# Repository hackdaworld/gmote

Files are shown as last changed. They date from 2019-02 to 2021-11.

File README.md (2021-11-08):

# GMote
[GMote](https://digidev.de/gmote) - The Generic LoRaWAN Node

GMote stands for Generic Mote.
It is meant to be a flexible (i.e. applicable in different scenarios for different purposes utilizing different sensors) IoT Node using the LoRa wireless data communication technology. 

The first GMote test version

The first test version was based on the Arduino Pro Mini, which requires very low power if you remove the LED and bypass the power regulator.
Once this proved to be a good idea, a slim version of the Mini Pro board (i.e. the ATMega 328PB) has been integrated and routed on the GMote circuit board.
At first, the Dragino LoRa Bee was the transceiving unit since we had good results with respect to range and usability.
In later versions, the relevant HopeRF modem (RFM95) chip was likewise integrated on the board due to availability and price. 

There are two PCB versions, a small and a mini version, which provide different amount of pin headers to connect various sensors or even actuators. 
Development of an ARM Cortex M0 based version is in progress.

The node is configurable via UART and (planned) LoRaWAN download frames.

It started within the Arduino framework and, as far as the AVR version is concerned, will stick to it to not loose the huge developer community.

## Most important

GMote is meant to become an all-purpose LoRaWAN node (and in fact a whole eco system).
Moreover, the design, hardware, firmware and software of the GMote project is open source and free to use without any restriction.
To enable everyone to participate, everything is kept as simple as possible, ranging from the low-level PCB design and firmware up to the high-level IoT platform app.

Since it aims to become a project for a hopefully huge community, let the GMote developers know what you think about it, about problems that occured, additional features that you require and everything you would like to have changed in the current realization. 
Anything on your mind?
Maybe to remove the RTC in favor of the internal watchdog timer to make the board even more simple (thereby accepting some inaccuracy in the periodicity of frames)? 
No I2C pinout or at least another version without?
A voltage regulator for a well defined supply but a shorter battery lifetime in return?
Whatever it is, let us know!

## Requirements

* ISP programmer, e.g. the [Pocket AVR Programmer](https://www.digikey.de/product-detail/de/sparkfun-electronics/PGM-09825/1568-1080-ND/5230949), to upload the firmware or an optional Arduino bootloader as you please.
* USB to serial converter (3.3V), e.g. the [FT231X Breakout](https://www.digikey.de/product-detail/de/sparkfun-electronics/BOB-13263/1568-1720-ND/7675364) for optionally uploading the firmware the Arduino way (via boot loader) and for serial communication and configuration. Strictly speaking, this is not required, since you could configure the node (i.e. program the EEPROM) via ISP. However, it is strongly suggested!
* A board (see below) produced by your favorite PCB manufacturer.
* The parts listed in the respective bill of materials.
* Soldering iron and solder.

## Hardware

### PCB

Small and mini version of the GMote LoRaWAN node

There are currently two versions ([small](pcb/small) and [mini](pcb/mini)) of the GMote LoRaWAN node, which are based on the ATMega 328PB and run quite reliably.
Moreover, there is one based on the [ARM MCU](pcb/arm), which is in very early stage and comes without any guarantee to work. We mean it!

You can find the available PCBs in the respective [PCB](pcb) directory
together with further details as well as the bill of materials and respective [DigiKey](https://www.digikey.de/) part numbers.

The boards are designed with [KiCad](http://kicad.org/).
A lot of PCB manufacturers directly support the KiCad PCB files.

The size of the SMD parts was chosen to be 0805 (2012) and hand soldering pads were used for the resistors and capacitors so you can DIY at home with a low cost soldering iron.
Caution: Patience required!

:warning: :warning:
The ATMega based boards are missing a pullup at the chipselect signal of the LoRa modem.
Please find details and a workaround in the [firmware section](#firmware).
:warning: :warning:

### Battery

The popular JST connector is used to connect the battery.
It is directly wired to VCC of the used ICs, no voltage regulator no polarity protection diodes!
Thus, be extremely careful when connecting your power supply.

GMote runs nicely with 3.7V LiPo batteries.
Higher voltages were not tested, so don't use higher voltages!
If you don't use the moisture or ultrasound distance sensor (these seem to require more than 3.3V), you can even run it with two AA(A) batteries (3V) or even accus (~2.8V).

## Firmware

All files can be found in the [firmware](firmware) location. 

### AVR ATMega 328PB fimrware

So far, you need the [Arduino IDE](https://www.arduino.cc/en/Main/Software) to build the firmware.
Moreover, the [LMIC library](https://github.com/matthijskooijman/arduino-lmic) is currently used to implement LoRaWAN.
Please follow the [instructions](https://github.com/matthijskooijman/arduino-lmic/#Installing) to include this library in your Arduino IDE.

Now you can build the firmware from the Arduino Sketch, [m328pb.ino](./firmware/mega328pb/m328pb.ino).\
Comment or uncomment the line
```c
#define PCB_MINI
```
in the very beginning of the sketch depending on the board you chose.

Alternatively, feel free to use one of the precompiled binaries.\
Mini: [m328pb_mini.hex](firmware/mega328pb/m328pb_mini.hex)\
Small: [m328pb_small.hex](firmware/mega328pb/m328pb_small.hex)

Since you build a GMote device from scratch, you start with a plain Atmega328P without an installed Arduino bootloader.
Use the ISP programmer and the [avrdude](https://www.nongnu.org/avrdude/) software to program either an optional Arduino bootloader or upload the GMote firmware directly.
To upload the firmware directly using the Pocket AVR Programmer, do
```
avrdude -patmega328pb -cusbtiny -v -Uflash:w:/path/to/m328pb_mini.hex:i
```
and adjust the path to the firmware hex file.
For disablinge the clock divider, which you have to do, run:
```
avrdude -patmega328pb -cusbtiny -v -Ulfuse:w:0xe2:m
```

:warning: :warning:
A pullup is required at the chipselect signal of the LoRa modem (pin 5 of the HopeRF or pin 14 of the ATMega).
Without it, programming the firmware or setting the fuse bits only works randomly because of the SPI LoRa modem disturbing the ISP programming process.
I am not sure why I didn't recognize this for the first few test devices.
Either there a different versions of the modem where some of them have an integrated pullup or it was simply by chance. 
I helped myself with a short wire applying VCC to the above mentioned pin during programming and setting the fuse bits.
There will be no board revision just fixing this bug since a new board is planned anyways.
Sorry for the inconvenience!
:warning: :warning:

### STM32F051 firmware

The version currently in development will be based on the *STM32F051K8T6* ARM Cortex M0 IC MCU operating at 48Mhz with 64KB FLASH and 8KB of embedded SRAM.

[Apache MyNewt](https://mynewt.apache.org/) as well as [Mbed OS](https://www.mbed.com/) are considered as an OS.

* MyNewt: First attempts can be found in [firmware/mynewt](firmware/mynewt) 
* Mbed OS: nothing yet ...

We keep you posted ...

## Sensors

Next to the very basic digital input sensing and ADC meassurements on the availabe IO and ADC pins, there are a couple of other sensors which require a slightly more special treatment.
At the moment, these are the ultrasound distance and the capacitive soil moisture sensor.

Soil moisture and ultrasound distance sensor

These are sensors you probably know already and where to buy them.
They were not designed by the GMote team.

However, in order to reduce costs and to simplify things, yet another soil moisture sensor based on the infamous *74HC14* hex inverting Schmitt trigger has been designed.
Here we go: [GMote Soil Moisture Sensor](pcb/sms).

## Utils and configuration

The GMote device is configured via the serial interface utilizing the USB to serial converter.
you can find the source code as well as installation and usage instructions in the [utils](utils) directory.

## Cases

To cover GMote and its sensors, a case was designed using [OpenSCAD](http://www.openscad.org/).
At the moment, the ultrasound distance and capacative moisture sensors are considered.

GMote Cases and sensors for illustration

The image illustrates the idea of the case and sensors.
Details and files can be found in the [cases](cases) directory.

## Backend 

ToDo

## Software 

ToDo

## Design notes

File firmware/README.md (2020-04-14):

# Firmware

## AVR ATMega328PB

Arduino Sketch: [m328pb.ino](mega328pb/m328pb.ino)

Precompiled binaries: [m328pb_mini.hex](mega328pb/m328pb_mini.hex) and [m328pb_small.hex](mega328pb/m328pb_small.hex)

## STM32 Cortex M0

First attempts porting [Apache MyNewt](https://mynewt.apache.org/) to the ARM based GMote board is located in [mynewt](mynewt).

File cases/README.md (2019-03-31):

# Cases

## Tasks

- [x] OpenSCAD and STL files of the Mini version
- [ ] Print and verify Mini version

## Mini 900

Case for the GMote Mini version suitable for batteries with dimensions not exceeding 48x32x6 mm .
I used a 900 mAh LiPo battery, that's where the 900 comes from.

The whole case consists of multiple parts, which you can all find within the *mini_900.scad* or the *mini_900.stl* file.
If your 3D printer or print service does not support multiple parts in one file, there are
- *mini_800_bottom.stl* for the bottom
- *mini_800_top.stl* for the top
- *mini_800_us_closing.stl* for the ultrasound sensor closings
- *mini_800_ms_closing.stl* for the moisture sensor closing
of the case.

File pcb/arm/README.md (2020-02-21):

# GMote on ARM
[GMote](https://digidev.de/gmote) - Generic LoRaWAN Node

## Schematics

Schematic of GMote on ARM

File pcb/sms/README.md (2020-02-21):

# GMote soil moisture sensor

## Bill of materials

| Designator | Quantity  | Part | DigiKey |
| --- | --- | --- | --- |
| R1 | 1 | R 0805 100k | | 
| R2 | 1 | R 0805 100 | | 
| C1 | 1 | C 0805 10u | | 
| J1 | 1 | Pin Header 2.54 | | 
| U1 | 1 | SOIC-14 74HC14  | | 

## Schematics

Schematic of GMote Soil Moisture Sensor

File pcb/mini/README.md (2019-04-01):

# GMote Mini
[GMote](https://digidev.de/gmote) - Mini Version of the Generic LoRaWAN Node

## Bill of materials

| Designator | Quantity  | Part | DigiKey |
| --- | --- |--- | --- |
| U1 | 1 | RFM95W-868S2 | 1597-1488-ND / RFM95W-915S2-ND |
| J2 | 1 | AVR-ISP-6 | 952-2121-ND |
| C1 | 1 | 10uF C | 1276-2399-1-ND |
| C2/3/4/7/8 | 5 | 0.1uF C | 399-9158-1-ND |
| J1 | 1 | 2 Pin Conn | 455-1704-ND |
| J3 | 1 | 9 Pin Conn | Pin Header or Screw Terminal |
| J6 | 1 | U.FL SMT | CONUFL001-SMD-TCT-ND |
| J9 | 1 | 1 Pin Conn | optional 7.6 cm antenna wire |
| JP1/2 | 2 | 2 Pin Conn | 952-2262-ND |
| R1/2/3 | 3 | 10k Resistor | RR12P10.0KDCT-ND |
| U2 | 1 | PCF8563 RTC  | 568-6650-1-ND |
| U3 | 1 | ATMEGA328PB  | ATMEGA328PB-AU-ND |
| Y2 | 1 | 32.768kHz | 535-10248-1-ND |
| J2 | 1 | 6 Pin Conn | 609-3263-ND |

## Schematics

Schematic of GMote Mini

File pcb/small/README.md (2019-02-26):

# GMote Small
[GMote](https://digidev.de/gmote) - Small Version of the Generic LoRaWAN Node

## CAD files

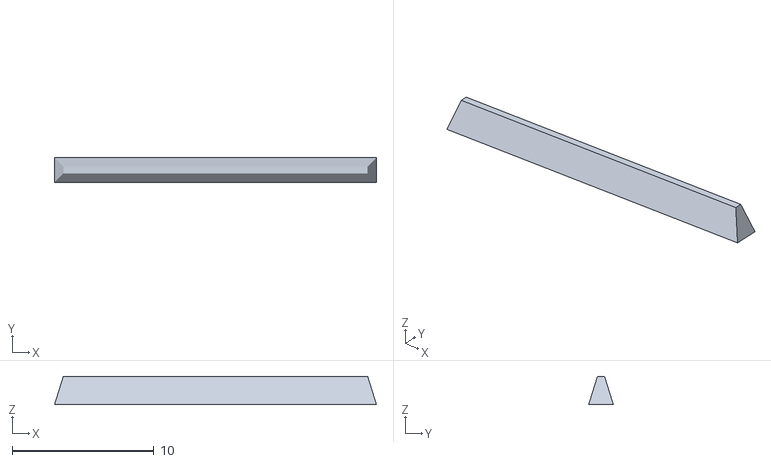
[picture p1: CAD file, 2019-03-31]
cases/mini_900_ms_closing.stl
22.8 x 1.75 x 2.01

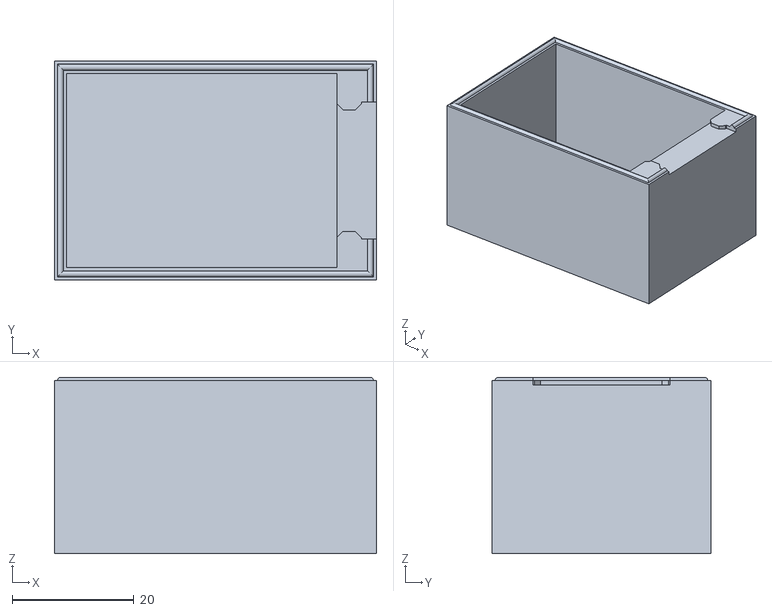
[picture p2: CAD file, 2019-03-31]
cases/mini_900_bottom.stl
53.0 x 36.0 x 29.0

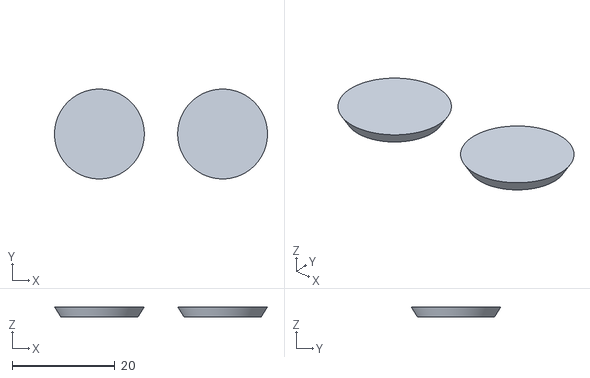
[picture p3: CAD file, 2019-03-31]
cases/mini_900_us_closing.stl
41.5 x 17.5 x 2.00

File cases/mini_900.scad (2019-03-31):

$fa=0.05;
$fs=0.05;

delta=0.01;
dfit=0.5;

bwd=2;

// moisture sensor
ms_l=86;
ms_w=22;
ms_t=1;
ms_rl=20.5;
ms_rlo=4.5;
ms_rli=2.5;
ms_rd=1.5;
ms_lt=96;
ms_cl=10;
ms_cw=10;
ms_ch=6;
ms_inside=25;
ms_rt=5*ms_t;

// us sensor
us_x=44;
us_y=20;
us_z=1.5;
us_r=16/2;
us_dx=10;
us_sh=13;

//bat_x=47;
bat_x=dfit+us_x+ms_rlo;
bat_y=32;
bat_z=6;

brd_x=34;
brd_y=25;
brd_z=25;

brd_rest_z=4;
brd_rest_y=2;
brd_t=1;


lockr=0.5;

ms_sh=bat_z+brd_z+2*bwd-ms_ch-ms_t/2;

module shim(w1,w2,d,h) {
	linear_extrude(height=h)
	polygon(points=[[-w1/2,0],[w1/2,0],[w2/2,d],[-w2/2,d]]);
}

module lock(x,y,rad) {
	translate([0,0,0]) rotate([0,90,0])
	cylinder(r=rad,h=x);
	translate([0,0,0]) rotate([-90,0,0])
	cylinder(r=rad,h=y);
	translate([x,0,0]) rotate([-90,0,0]) 
	cylinder(r=rad,h=y);
	translate([0,y,0]) rotate([0,90,0])
	cylinder(r=rad,h=x);
	intersection() {
		translate([-rad,0,0]) rotate([0,90,0])
		cylinder(r=rad,h=x+2*rad);
		translate([0,-rad,0]) rotate([-90,0,0])
		cylinder(r=rad,h=y+2*rad);
	}
	intersection() {
		translate([-rad,0,0]) rotate([0,90,0])
		cylinder(r=rad,h=x+2*rad);
		translate([x,-rad,0]) rotate([-90,0,0]) 
		cylinder(r=rad,h=y+2*rad);
	}
	intersection() {
		translate([x,-rad,0]) rotate([-90,0,0]) 
		cylinder(r=rad,h=y+2*rad);
		translate([-rad,y,0]) rotate([0,90,0])
		cylinder(r=rad,h=x+2*rad);
	}
	intersection() {
		translate([-rad,y,0]) rotate([0,90,0])
		cylinder(r=rad,h=x+2*rad);
		translate([0,-rad,0]) rotate([-90,0,0])
		cylinder(r=rad,h=y+2*rad);
	}
}

module fullcase02(dbg_x,dbg_y,dbg_z) {

// body
difference() {
	hull() {
		cube([bat_x+2*bwd,bat_y+2*bwd,bat_z+2*bwd+brd_z+bwd]);
	}
	union() {
		// volume
		translate([bwd,bwd,bwd])
			cube([bat_x+dbg_x,bat_y,bat_z+bwd+brd_z+dbg_z]);
		// moisture sensor slot
		translate([bat_x+bwd-delta,bwd+(bat_y-ms_w)/2-dfit/2,bat_z+2*bwd+brd_z-ms_ch-ms_t-dfit/2])
			cube([bwd+2*delta,ms_w+dfit,ms_t+dfit]);
		// us sensor openings
		translate([bwd+dfit+us_dx,bwd+dfit+us_y/2,bat_z+brd_z+2*bwd-delta]) {
			cylinder(r=us_r+dfit/2,h=bwd+2*delta);
			translate([us_x-2*us_dx,0,0])
				cylinder(r=us_r+dfit/2,h=bwd+2*delta);
		}
		// text
		translate([2.5*bwd,1.55*(bat_y/2+bwd),bat_z+brd_z+2.75*bwd])
		linear_extrude(height=bwd/4+delta)
				text("GMote",
				     font="Liberation Sans:style=Bold Italic",
				     valign="center",
				     size=8
				);
		translate([bat_x-1.8*bwd,1.5*bat_y/2,bat_z+brd_z+2.75*bwd])
		rotate([0,0,90])
		linear_extrude(height=bwd/4+delta)
				text("Mini",
				     font="Liberation Sans:style=Bold Italic",
				     valign="center",
				     size=3
				);
	}
}

// sensor rest (moisture)
translate([bat_x+2*bwd-(ms_inside-ms_rl),0,bat_z+brd_z+2*bwd-ms_ch-ms_t-ms_rt/2]) {
	// moisture
	hull() {
		translate([-(ms_rlo-dfit)/2,0,0])
			cube([ms_rlo-dfit,delta,ms_rt]);
		translate([0,bwd+(bat_y-ms_w)/2,0])
			shim(ms_rlo-dfit,ms_rli-dfit,ms_rd-dfit,ms_rt);
	}
	translate([0,bwd,0])
		cube([ms_inside-ms_rl,(bat_y-ms_w)/2-dfit/2,ms_rt]);
	hull() {
		translate([-(ms_rlo-dfit)/2,bat_y+2*bwd,0])
			cube([ms_rlo-dfit,delta,ms_rt]);
		translate([0,bat_y+bwd-(bat_y-ms_w)/2,0])
			shim(ms_rlo-dfit,ms_rli-dfit,-ms_rd+dfit,ms_rt);
	}
	translate([0,bat_y+bwd-(bat_y-ms_w)/2+dfit/2,0])
		cube([ms_inside-ms_rl,(bat_y-ms_w)/2,ms_rt]);
	// ground plate
	translate([-(ms_rlo-dfit)/2,0,0])
		cube([ms_inside-ms_rl,bat_y+2*bwd,ms_rt/2-dfit/2]);

	// us additional rest
	/*
	translate([-bat_x-bwd+(ms_inside-ms_rl),bwd,0])
		cube([bwd,bwd,ms_rt]);
	translate([-bat_x-bwd+(ms_inside-ms_rl),us_y,0])
		cube([bwd,bwd,ms_rt]);
	*/
}

}

module case_bottom() {
	intersection() {
		fullcase02(0,0,0);
		cube([100,100,ms_sh]);
	}
	difference() {
		translate([bwd/2,bwd/2,ms_sh])
			lock(bat_x+bwd,bat_y+bwd,lockr);
		translate([bwd,bwd+(bat_y-ms_w)/2-dfit/2,0])
			cube([100,ms_w+dfit,100]);
	}
}

module case_top() {
	translate([0,0,-ms_sh]) {
		//rotate([-110,0,0])
		difference() {
		intersection() {
			fullcase02(0,0,0);
			translate([0,0,ms_sh])
				cube([100,100,100]);
		}
		translate([bwd/2,bwd/2,ms_sh])
			lock(bat_x+bwd,bat_y+bwd,lockr);
		}
	}
}

// sensors

module us_sensor() {
	color("red") 
		cube([us_x,us_y,us_z]);
	color("silver") {
		translate([us_dx,us_y/2,us_z])
			cylinder(r=us_r,h=us_sh);
		translate([us_x-us_dx,us_y/2,us_z])
			cylinder(r=us_r,h=us_sh);
	}
}

module ms_sensor() {
	color("SaddleBrown") {

	difference() {
		cube([ms_l,ms_w,ms_t]);
		union() {
			translate([ms_rl,0,-delta]) {
				hull() {
					shim(ms_rlo,ms_rli,ms_rd,ms_t+2*delta);
					translate([-ms_rlo/2,-1,0])
						cube([ms_rlo,1,ms_t]);
				}
				translate([0,ms_w-ms_rd,0]) hull() {
					shim(ms_rli,ms_rlo,ms_rd,ms_t+2*delta);
					translate([-ms_rlo/2,ms_rd,0])
						cube([ms_rlo,1,ms_t]);
				}
			}
		 }
	}
	// tip
	translate([ms_l-1,0,0]) {
		hull() {
			cube([1,ms_w,ms_t]);
			translate([ms_lt-ms_l,ms_w/2,0]) cube([0.01,0.01,ms_t]);
		}
	}

	}
	color("grey") {
		translate([-ms_cl/2,(ms_w-ms_cw)/2,ms_t])
		cube([ms_cl,ms_cw,ms_ch]);
	}
}

module ms_closing() {
	hull() {
		cube([ms_w+1.5*dfit,ms_t+1.5*dfit,delta]);
		translate([1.25*dfit,1.25*dfit,bwd])
			cube([ms_w-dfit,ms_t-dfit,delta]);
	}
}

module us_closing() {
	cylinder(r2=us_r+1.5*dfit,r1=us_r-dfit,h=bwd);
	translate([us_x-2*us_dx,0,0])
		cylinder(r2=us_r+1.5*dfit,r1=us_r-dfit,h=bwd);
}

// printable

// everything
/**/
translate([0,0,0]) {
	translate([0,bat_y+4*bwd,0]) {
		case_bottom();
	}
	case_top();
	translate([bat_x+4*bwd+us_dx,us_r+bwd,0])
		us_closing();
	translate([bat_x+4*bwd+us_dx,bat_y-2*bwd,0])
		ms_closing();
}
/**/

// bottom
//case_bottom();
// top
//case_top();
// us closing
//us_closing();
// ms closing
//ms_closing();

// showcase

/*
translate([0,2*(bat_y+4*bwd),0]) {
	fullcase02(0,0,0);
	translate([bwd+dfit,bwd+dfit,bat_z+brd_z+2*bwd-us_z-dfit])
		us_sensor();
	translate([bwd+bat_x+bwd+2*dfit,bwd+(bat_y-ms_w)/2-0.75*dfit,ms_sh+ms_t/2+dfit])
		rotate([0,-90,0]) rotate([0,0,90]) ms_closing();
}

translate([0,3*(bat_y+4*bwd),0]) {
	fullcase02(0,0,0);
	translate([bat_x+2*bwd-ms_inside,(bat_y+2*bwd-ms_w)/2,bat_z+brd_z+2*bwd-ms_ch-ms_t])
		ms_sensor();
	translate([bwd+us_dx+dfit,bwd+us_y/2+dfit,bat_z+brd_z+2*bwd+2*dfit]) us_closing();
}

translate([bat_x+6*bwd,bat_y+4*bwd,0]) {
	ms_sensor();
}

translate([bat_x+6*bwd,bat_y+6*bwd+ms_w,0]) {
	us_sensor();
}

translate([bat_x+6*bwd,3.2*(bat_y+4*bwd),ms_ch+ms_t+bwd]) {
	rotate([-180,0,0]) case_top();
}

*/

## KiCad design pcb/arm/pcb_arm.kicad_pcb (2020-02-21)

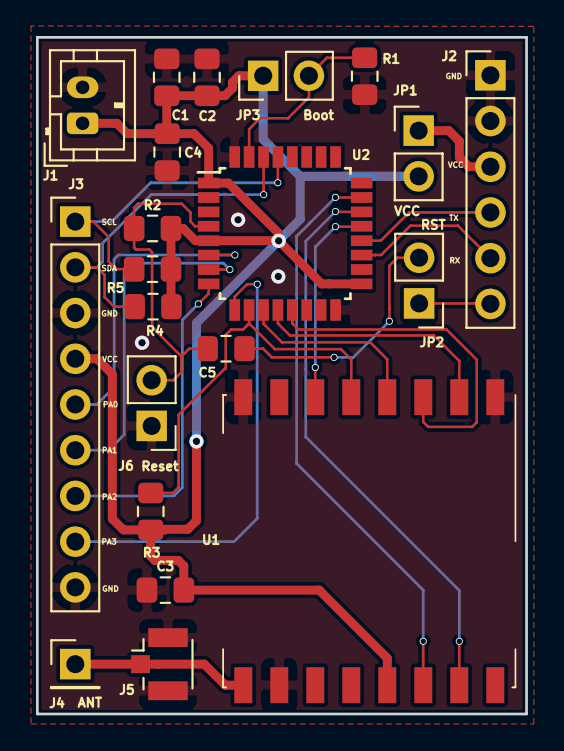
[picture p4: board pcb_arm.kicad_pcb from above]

Board: 2 copper layers, 27.2 x 37.6 mm, 21 parts (0 on the bottom side), 23 nets.

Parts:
C1, C3, C4, C5: 100nF; C_0805_2012Metric_Pad1.15x1.40mm_HandSolder
C2: 10uF; C_0805_2012Metric_Pad1.15x1.40mm_HandSolder
J1: JST_POWER; JST_PH_B2B-PH-K_1x02_P2.00mm_Vertical
J2: 231X_Breakout; PinHeader_1x06_P2.54mm_Vertical
J3: IO_ADC_PINOUT; PinHeader_1x09_P2.54mm_Vertical
J4: ANT_WIRE; PinHeader_1x01_P2.54mm_Vertical
J5: Conn_Coaxial; U.FL_Hirose_U.FL-R-SMT-1_Vertical
J6: RST_PIN; PinHeader_1x02_P2.54mm_Vertical
JP1, JP2, JP3: Jumper; PinHeader_1x02_P2.54mm_Vertical
R1, R2, R3, R4, R5: 10k; R_0805_2012Metric_Pad1.15x1.40mm_HandSolder
U1: RFM95W-868S2; HOPERF_RFM9XW_SMD
U2: STM32F051K8Tx; LQFP-32_7x7mm_P0.8mm

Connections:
231X_RX: J2.5, U2.19
231X_TX: J2.4, U2.20
ANT: J4.1, J5.1, U1.9
ARM_BOOT0: JP3.2, R1.1, U2.31
ARM_RST: C5.1, J6.2, R2.1, U2.4
ARM_SCL: J3.1, R5.1, U2.29
ARM_SDA: J3.2, R4.1, U2.30
GND: C1.2, C2.2, C3.2, C4.2, J1.2, J2.1, J2.2, J3.3, J3.9, J5.2, J6.1, R1.2, U1.1, U1.8, U1.10, U2.16, U2.32
unnamed: J2.3, JP1.1
unnamed: J2.6, JP2.1
PA0: J3.5, U2.6
PA1: J3.6, U2.7
PA2: J3.7, U2.8
PA3: J3.8, U2.9
RFM95_DIO0: U1.14, U2.23
RFM95_DIO1: U1.15, U2.22
RFM95_RST: U1.6, U2.21
RST: C5.2, JP2.2
SPI_MISO: U1.2, U2.12
SPI_MOSI: U1.3, U2.13
SPI_NSS: R3.1, U1.5, U2.10
SPI_SCK: U1.4, U2.11
VCC: C1.1, C2.1, C3.1, C4.1, J1.1, J3.4, JP1.2, JP3.1, R2.2, R3.2, R4.2, R5.2, U1.13, U2.1, U2.5, U2.17

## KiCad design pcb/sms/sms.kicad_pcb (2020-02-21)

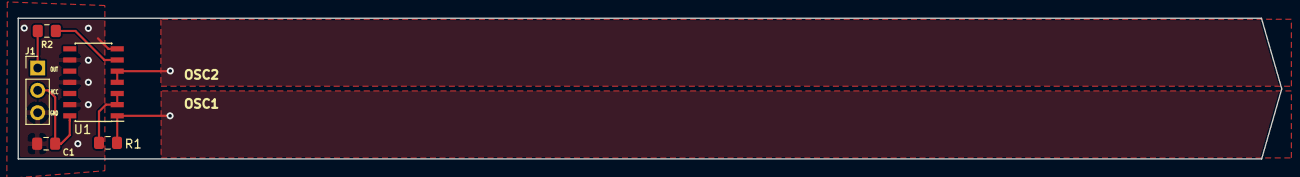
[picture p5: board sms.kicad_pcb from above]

Board: 2 copper layers, 143.7 x 16.0 mm, 5 parts (0 on the bottom side), 7 nets.

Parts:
C1: 10u; C_0805_2012Metric_Pad1.15x1.40mm_HandSolder
J1: Conn_01x03_Male; PinHeader_1x03_P2.54mm_Vertical
R1: 100k; R_0805_2012Metric_Pad1.15x1.40mm_HandSolder
R2: 100; R_0805_2012Metric_Pad1.15x1.40mm_HandSolder
U1: 74HC14; SOIC-14_3.9x8.7mm_P1.27mm

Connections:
GND: C1.2, J1.3, U1.7, U1.9, U1.11, U1.13
unnamed: R1.1, U1.2, U1.3
unnamed: R2.2, U1.6
OSC1: R1.2, U1.1
OSC2: U1.4, U1.5
OUT: J1.1, R2.1
VCC: C1.1, J1.2, U1.14

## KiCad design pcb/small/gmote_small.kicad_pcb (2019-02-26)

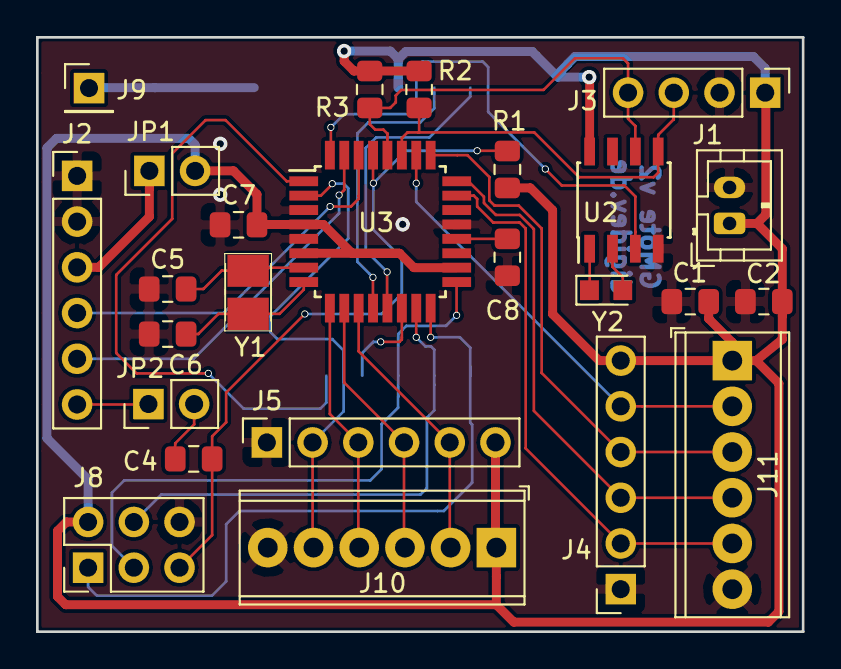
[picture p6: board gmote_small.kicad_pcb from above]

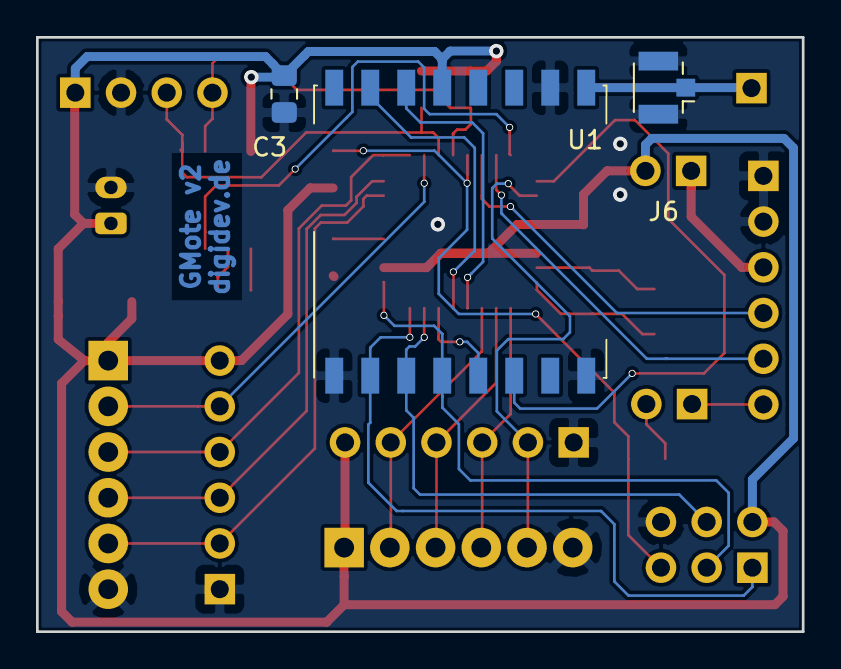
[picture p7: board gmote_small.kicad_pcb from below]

Board: 2 copper layers, 42.5 x 33.0 mm, 28 parts (3 on the bottom side), 32 nets.

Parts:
C1: 10uF; C_0805_2012Metric_Pad1.15x1.40mm_HandSolder
C2, C3, C4, C7, C8: 0.1uF; C_0805_2012Metric_Pad1.15x1.40mm_HandSolder
C5, C6: 16pF; C_0805_2012Metric_Pad1.15x1.40mm_HandSolder
J1: Conn_01x02_Male; JST_PH_B2B-PH-K_1x02_P2.00mm_Vertical
J2: Conn_01x06_Male; PinHeader_1x06_P2.54mm_Vertical
J3: Conn_01x04_Male; PinHeader_1x04_P2.54mm_Vertical
J4: Conn_ADC; PinSocket_1x06_P2.54mm_Vertical
J5: Conn_IO; PinSocket_1x06_P2.54mm_Vertical
J6: Ant_UFL; U.FL_Hirose_U.FL-R-SMT-1_Vertical
J8: AVR-ISP-6; PinHeader_2x03_P2.54mm_Vertical
J9: Conn_01x01_Male; PinHeader_1x01_P2.54mm_Vertical
J10: Screw_Terminal_IO; TerminalBlock_Phoenix_MPT-0,5-6-2.54_1x06_P2.54mm_Horizontal
J11: Screw_Terminal_ADC; TerminalBlock_Phoenix_MPT-0,5-6-2.54_1x06_P2.54mm_Horizontal
JP1, JP2: Jumper; PinHeader_1x02_P2.54mm_Vertical
R1, R2, R3: 10k; R_0805_2012Metric_Pad1.15x1.40mm_HandSolder
U1: RFM95W-868S2; HOPERF_RFM9XW_SMD
U2: PCF8563T; SOIC-8_3.9x4.9mm_P1.27mm
U3: ATmega328P-AU; TQFP-32_7x7mm_P0.8mm
Y1: 8Mhz; Crystal_3.0x2.5_HandSoldering
Y2: 32.768kHz; Crystal_SMD_2012-2Pin_2.0x1.2mm_HandSoldering

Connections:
ADC0: J4.2, J11.5, U3.23
ADC1: J4.3, J11.4, U3.24
ADC2: J4.4, J11.3, U3.25
ADC3: J4.5, J11.2, U3.26
ANT: J6.1, J9.1, U1.9
DTR: C4.1, JP2.2
GND: C1.2, C2.2, C3.1, C5.1, C6.1, C7.1, C8.2, J1.2, J2.1, J2.2, J3.2, J4.1, J5.1, J6.2, J8.6, J10.6, J11.6, U1.1, U1.8, U1.10, U2.4, U3.3, U3.5, U3.21
INT0: U2.3, U3.32
MISO: J8.1, U1.2, U3.16
MOSI: J8.4, U1.3, U3.15
unnamed: C8.1, U3.20
unnamed: J2.3, JP1.1
unnamed: J2.6, JP2.1
unnamed: U2.1, Y2.1
unnamed: U2.2, Y2.2
PB0: U1.14, U3.12
PB1: U1.15, U3.13
PD3: U1.6, U3.1
PD4: J5.2, J10.5, U3.2
PD5: J5.3, J10.4, U3.9
PD6: J5.4, J10.3, U3.10
PD7: J5.5, J10.2, U3.11
RXI: J2.4, U3.30
Reset: C4.2, J8.5, R1.1, U3.29
SCK: J8.3, U1.4, U3.17
SCL: J3.4, R3.2, U2.6, U3.28
SDA: J3.3, R2.2, U2.5, U3.27
SS: U1.5, U3.14
TXO: J2.5, U3.31
VCC: C1.1, C2.1, C3.2, C7.2, J1.1, J3.1, J4.6, J5.6, J8.2, J10.1, J11.1, JP1.2, R1.2, R2.1, R3.1, U1.13, U2.8, U3.4, U3.6, U3.18
XTAL1: C5.2, U3.7, Y1.1
XTAL2: C6.2, U3.8, Y1.2

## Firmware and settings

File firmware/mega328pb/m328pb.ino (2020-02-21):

/*******************************************************************************
   
   GMote - Generic LoRaWAN Node

   Author: frank@hackdaworld.org
   HTTP: https://digidev.de/gmote

   Based on the OTAA TTN example sketch of the lmic Arduino library.
   
 *******************************************************************************/

#include <lmic.h>
#include <hal/hal.h>
#include <SPI.h>

#include <avr/boot.h>
#include <EEPROM.h>

#include <avr/sleep.h>
#include <avr/wdt.h>

#include <Wire.h>

#define MST_DD_VCC  A0
#define MST_DD_OUT  A1

#define PCB_MINI

#ifdef PCB_MINI
  // PCB Mini
  #define LORA_RST  5
  #define US_ECHO   A0
  #define US_TRIG   A1
  #define US_VCC    A2
#else
  // PCB Small
  #define LORA_RST  3
  #define US_ECHO   4
  #define US_TRIG   5
  #define US_VCC    6
#endif

//
// LMIC LoRaWAN stuff
//

// little endian AppEUI
// For TTN issued EUIs the last bytes should be 0xD5, 0xB3, 0x70.
uint8_t APPEUI[8];
#define EEPROM_OFFSET_APPEUI 8
void os_getArtEui (u1_t* buf) {
  for(uint8_t i=0;i<8;i++)
    buf[i]=APPEUI[7-i];
}

// little endian DevEUI
uint8_t DEVEUI[8];
#define EEPROM_OFFSET_DEVEUI 0 
void os_getDevEui (u1_t* buf) {
  for(uint8_t i=0;i<8;i++)
    buf[i]=DEVEUI[7-i];
}

// big endian application key
uint8_t APPKEY[16];
#define EEPROM_OFFSET_APPKEY 16
void os_getDevKey (u1_t* buf) {
  memcpy(buf, APPKEY, 16);
}

// data
static uint8_t data[32];
static uint8_t data_old[32];

// memory for the sendjob function
static osjob_t sendjob;

// Pin mapping
const lmic_pinmap lmic_pins = {
  .nss = 10,
  .rxtx = LMIC_UNUSED_PIN,
  .rst = LORA_RST,
  .dio = {8, 9, LMIC_UNUSED_PIN},
};

//
// GMote configuration & state machine
//

// Serial
uint8_t serGM[10];

// GMote configuration
uint8_t confGM[8];
#define EEPROM_OFFSET_CONFGM 32

/* byte:  7       6    5    4           3           2                    1    0
 *        custom  rfu  rfu  keep alive  sleep time  temperature offeset  rfu  type
 *        
 * rfu: reserved for future use
 * custom: whatever you require
 */

#define SENSOR_TYPE           0
#define TEMP_OFFSET           2
#define SLEEP_TIME            3
#define KEEP_ALIVE            4
#define CUSTOM                7

#define SENSORS_EXT           0
#define SENSOR_ULTRASONIC     0x01
#define SENSOR_IO             0x02
#define SENSOR_LOUDNESS       0x04
#define SENSOR_MOISTURE       0x08
#define SENSOR_MOISTURE_ADC   0x10

#define SENSORS_INT           1
#define SENSOR_BAT_ADC        0x01
#define SENSOR_BAT_TEMP       0x02

// GMote states
uint8_t state=1;
#define STARTUP 1
#define RTC_INITIALIZED 2
#define SENDING 3  
#define STARTUP_DELAY 2000
uint8_t keep_alive=0;
uint8_t keep_alive_cnt=0;

// rtc timer
#define RTC_I2C_ADDR 0x51
#define RTC_ADDR_CS2 0x01
#define RTC_CS2 0x11 // pulsed timer interrupt enabled, timer interrupt enabled, timer flag cleared 
#define RTC_ADDR_TC 0x0e
#define RTC_TC 0x83 // timer enabled & src clock freq 1/60 hz (minute)
uint8_t rtc_t = 1; // timer counter, default 1 (minute)

// Serial communication
uint8_t inSerBuf[36];
uint8_t inSerCnt = 0;

// LMIC callbacks
void onEvent (ev_t ev) {
  Serial.print(os_getTime());
  Serial.print(": ");
  switch (ev) {
    case EV_SCAN_TIMEOUT:
      Serial.println(F("EV_SCAN_TIMEOUT"));
      break;
    case EV_BEACON_FOUND:
      Serial.println(F("EV_BEACON_FOUND"));
      break;
    case EV_BEACON_MISSED:
      Serial.println(F("EV_BEACON_MISSED"));
      break;
    case EV_BEACON_TRACKED:
      Serial.println(F("EV_BEACON_TRACKED"));
      break;
    case EV_JOINING:
      Serial.println(F("EV_JOINING"));
      break;
    case EV_JOINED:
      Serial.println(F("EV_JOINED"));
      // Disable link check validation (automatically enabled
      // during join, but not supported by TTN at this time).
      LMIC_setLinkCheckMode(0);
      break;
    case EV_RFU1:
      Serial.println(F("EV_RFU1"));
      break;
    case EV_JOIN_FAILED:
      Serial.println(F("EV_JOIN_FAILED"));
      break;
    case EV_REJOIN_FAILED:
      Serial.println(F("EV_REJOIN_FAILED"));
      break;
    case EV_TXCOMPLETE:
      Serial.println(F("EV_TXCOMPLETE"));
      if (LMIC.txrxFlags & TXRX_ACK)
        Serial.println(F("Received ack"));
      if (LMIC.dataLen) {
        Serial.println(F("Received "));
        Serial.println(LMIC.dataLen);
        Serial.println(F(" bytes of payload"));
        // new config
        if(LMIC.dataLen!=8) {
          Serial.println(F("Wrong payload length, doing nothing!"));
        }
        else {
          Serial.print(F("New configuration: "));
          for(uint8_t i=0;i<8;i++) {
            confGM[i]=LMIC.frame[LMIC.dataBeg+i];
            EEPROM.write(EEPROM_OFFSET_CONFGM+i,confGM[i]);
            Serial.print(confGM[i],HEX);
          }
          Serial.println();
          bitClear(state,RTC_INITIALIZED);
        }
      }
      
      // Schedule next transmission
      rtc_t = confGM[SLEEP_TIME];
      if(rtc_t == 0) {
        Serial.println(F("Immediate action ..."));
        do_send(&sendjob);
      }
      // initial rtc setup
      if(!(state&bit(RTC_INITIALIZED)))
        rtc_setup();

      // GMote state
      bitClear(state,SENDING);

      break;
    case EV_LOST_TSYNC:
      Serial.println(F("EV_LOST_TSYNC"));
      break;
    case EV_RESET:
      Serial.println(F("EV_RESET"));
      break;
    case EV_RXCOMPLETE:
      // data received in ping slot
      Serial.println(F("EV_RXCOMPLETE"));
      break;
    case EV_LINK_DEAD:
      Serial.println(F("EV_LINK_DEAD"));
      break;
    case EV_LINK_ALIVE:
      Serial.println(F("EV_LINK_ALIVE"));
      break;
    default:
      Serial.println(F("Unknown event"));
      break;
  }
  // enter_sleep
  if(!(state&bit(SENDING)))
    enter_sleep();    
}

// LMIC send function
void do_send(osjob_t* j) {
  // Check if there is not a current TX/RX job running
  if (LMIC.opmode & OP_TXRXPEND) {
    Serial.println(F("OP_TXRXPEND, not sending"));
  } else {
    uint8_t datalen;
    // sensor config
    data[0]=confGM[SENSORS_EXT];
    datalen=1;

    // external sensor data
    
    if(confGM[SENSORS_EXT]&SENSOR_ULTRASONIC) {
      *((uint16_t *)(data+datalen))=us();
      datalen+=2;      
    }
    if(confGM[SENSORS_EXT]&SENSOR_IO) {
      data[datalen]=io();
      datalen+=1;
    }
    if(confGM[SENSORS_EXT]&SENSOR_LOUDNESS) {
      data[datalen]=loudness();
      datalen+=1;
    }
    if(confGM[SENSORS_EXT]&SENSOR_MOISTURE) {
      //data[datalen]=moisture();
      data[datalen]=moisture_dd();
      datalen+=1;
    }
    if(confGM[SENSORS_EXT]&SENSOR_MOISTURE_ADC) {
      *((uint16_t *)(data+datalen))=moisture_analog();
      datalen+=2;
    }

    // internal sensors (bat & temp)

    data[datalen]=adc_bat();
    datalen+=1;
    data[datalen]=adc_temp();
    datalen+=1;

    keep_alive_cnt+=1;  
    if(memcmp(data_old,data,datalen-2) || keep_alive_cnt>=keep_alive) {
      // new data
      // reset keep alive counter
      keep_alive_cnt=0;
      // copy data
      memcpy(data_old,data,datalen-2);
      // Prepare upstream data transmission at the next possible time
      bitSet(state,SENDING);
      LMIC_setTxData2(1, data, datalen, 0);
      Serial.println(F("Packet queued"));
    }
    else {
      Serial.println(F("Old data"));
      enter_sleep();
    }
 
  }
}

void rtc_setup() {
  uint8_t result;
  Serial.print(F("RTC setup - control status 2: "));
  Wire.begin();
  Wire.beginTransmission(RTC_I2C_ADDR);
  Wire.write(RTC_ADDR_CS2);
  Wire.write(RTC_CS2);
  result = Wire.endTransmission();
  Serial.println(result);
  Serial.print(F("RTC setup - timer control (rtc_t="));
  Serial.print(rtc_t);
  Serial.print(F("): "));
  Wire.begin();
  Wire.beginTransmission(RTC_I2C_ADDR);
  Wire.write(RTC_ADDR_TC);
  Wire.write(RTC_TC);
  Wire.write(rtc_t);
  result = Wire.endTransmission();
  Serial.println(result);
  bitSet(state,RTC_INITIALIZED);
}

// external sensors

uint8_t io() {
  // io: 5 = vcc, 6 = input
  pinMode(5,INPUT);
  pinMode(6,OUTPUT);
  // apply voltage
  digitalWrite(6,HIGH);
  delay(50);
  uint8_t in = digitalRead(5);
  // shut down voltage
  digitalWrite(6,LOW);
  Serial.print(F("IO: "));
  Serial.println(in,HEX);
  return(in);  
}

uint16_t us() {
  // io: echo = 4, trigger = 5, vcc = 6
  pinMode(US_VCC,OUTPUT);
  pinMode(US_TRIG,OUTPUT);
  pinMode(US_ECHO,INPUT);
  // power us sensor
  digitalWrite(US_VCC,HIGH);
  delay(200);
  // reset / trigger sensor
  digitalWrite(US_TRIG,LOW);
  delayMicroseconds(5);
  digitalWrite(US_TRIG,HIGH);
  delayMicroseconds(10);
  digitalWrite(US_TRIG,LOW);
  // count high time
  unsigned long pulse=pulseIn(US_ECHO,HIGH);
  digitalWrite(US_VCC,LOW);
  if(pulse>65535)
    pulse=0;
  Serial.print(F("US: "));
  Serial.println(pulse);
  return(pulse&0xffff);
}

uint8_t loudness() {
  // power on sensor
  pinMode(A3,OUTPUT);
  digitalWrite(A3,HIGH);
  delay(500);
  uint16_t mean=0;
  Serial.print("DBG: ");
  for(uint8_t i=0; i<4; i++) {
    mean+=analogRead(A1);
    Serial.print(mean);
    Serial.print(" ");
    delay(100); 
  }
  uint8_t loudness=mean>>2;
  // power down
  digitalWrite(A3,LOW);
  Serial.print(F("L: "));
  Serial.println(loudness);
  return loudness; 
}

uint8_t moisture () {
  pinMode(6,OUTPUT);
  pinMode(5,INPUT);
  digitalWrite(6,HIGH);
  TCCR1A = 0;
  TCNT1 = 0;            // Reset Counter
  delay(10);            // Delay for stable channel selection
  bitSet(TCCR1B, CS12); // Select counter clock
  bitSet(TCCR1B, CS11); // Count on rising edge
  delay(100);           // Count for 50mS
  TCCR1B = 0;           // Stop counting
  digitalWrite(6,LOW);
  uint16_t tc=TCNT1;
  Serial.print(F("M: "));
  Serial.println(tc);
  uint8_t moisture=tc>>8;
  return moisture;
}

uint8_t moisture_dd() {
  // make it an input (again)
  pinMode(MST_DD_OUT,INPUT_PULLUP);
  delay(50);
  pinMode(MST_DD_VCC,OUTPUT);
  digitalWrite(MST_DD_VCC,HIGH);
  delay(200);
  uint8_t moisture=pulseIn(MST_DD_OUT,LOW);
  digitalWrite(MST_DD_VCC,LOW);
  Serial.print(F("M_DD: "));
  Serial.println(moisture);
  // maybe current flows via pullup -> mode output, low
  delay(50);
  pinMode(MST_DD_OUT,OUTPUT);
  digitalWrite(MST_DD_OUT,LOW);
  return moisture;
}

uint16_t moisture_analog() {
  uint16_t ar;
  uint8_t oldADMUX = ADMUX;

  // enable ADC
  ADCSRA |= (1 << ADEN);
  // refs1/0 => 01 (use vcc as a reference), mux3/2/1/0 => 0001 (ADC1)
  ADMUX = (0 << REFS1) | (1 << REFS0) | (0 << ADLAR) | (0 << MUX3) | (0 << MUX2) | (0 << MUX1) | (1 << MUX0);

  pinMode(A0,OUTPUT);
  pinMode(A1,INPUT);
  digitalWrite(A0,HIGH);
  delay(200);

  ar=0;
  for(uint8_t i=0;i<3;i++) {
    ADCSRA |= (1 << ADSC);
    while (((ADCSRA & (1 << ADSC)) != 0));
    // skip first conversion
    if(i>0) ar+=ADC;
  }
  
  digitalWrite(A0,LOW);

  // mean of remaining 2 samples
  ar=ar>>1;
   
  ADMUX = oldADMUX;
  
  Serial.print(F("M_A HV: "));
  Serial.println(ar);

  return ar;
}

// internal sensors

uint8_t adc_bat() {
  uint16_t val;
  uint16_t tmp;
  uint8_t oldADMUX = ADMUX;

  // enable ADC
  ADCSRA |= (1 << ADEN);
  // refs1/0 => 01 (use vcc as a reference), mux3/2/1/0 => 1110 (1.1v endpoint)
  ADMUX = (0 << REFS1) | (1 << REFS0) | (0 << ADLAR) | (1 << MUX3) | (1 << MUX2) | (1 << MUX1) | (0 << MUX0);
  delay(20); // settle

  tmp=0;
  for(uint8_t i=0;i<3;i++) {
    ADCSRA |= (1 << ADSC);
    while (((ADCSRA & (1 << ADSC)) != 0));
    // skip first conversion
    if(i>0) tmp+=ADC;
  }
  // mean of remaining 2 samples
  tmp=tmp>>1;
   
  // v_endpoint = adc / 1023 * v_ref, v_ref = vcc, v_endpoint = 1.1 => vcc = 1.1 * 1023 / adc
  val = ((1100L * 1023)/tmp);
  uint8_t result = val>>5;
  ADMUX = oldADMUX;
  Serial.print(F("BAT ADC: "));
  Serial.print(val);
  Serial.print(F(" / "));
  Serial.println(result);
  return result;
}

uint8_t adc_temp() {
  uint8_t oldADMUX = ADMUX;
  uint16_t tmp;
  // enable ADC
  //ADCSRA |= (1 << ADEN);
  // refs1/0 => 11 (internal 1.1v as a reference), mux3/2/1/0 => 1000 (temperature sensor endpoint)
  ADMUX = (1 << REFS1) | (1 << REFS0) | (0 << ADLAR) | (1 << MUX3) | (0 << MUX2) | (0 << MUX1) | (0 << MUX0);
  delay(20);
  tmp=0;
  for(uint8_t i=0;i<3;i++) {
    ADCSRA |= (1 << ADSC);
    while (((ADCSRA & (1 << ADSC)) != 0));
    // skip first conversion
    if(i>0) tmp+=ADC;
  }
  // mean of remaining 2 samples
  tmp=tmp>>1;
  uint8_t result = (uint8_t)(tmp-335);
  ADMUX = oldADMUX;
  Serial.print(F("TEMP ADC: "));
  if(confGM[TEMP_OFFSET]==0xff) {
    Serial.println(result);
    return result;
  }
  else {
    Serial.print(result);
    Serial.print(F(" / "));
    Serial.println(result+confGM[TEMP_OFFSET]);
    return result+confGM[TEMP_OFFSET];
  }
}

//
// setup
//

void setup() {
  Serial.begin(9600);
  Serial.print(F("MCUSR: ")); Serial.println(MCUSR,HEX);
  Serial.println(F("GMote startup"));

  Serial.print(F("FW version: "));
  #ifdef PCB_MINI
  Serial.println(F("MINI"));
  #else
  Serial.println(F("SMALL"));
  #endif

  bool virgin=true;
  uint8_t i;

  // External interrupt 0
  pinMode(2,INPUT_PULLUP);  
  
  // Serial
  Serial.print(F("Serial:"));
  for(i=0;i<10;i++) {
    Serial.print(F(" "));
    serGM[i] = boot_signature_byte_get(i+14);
    Serial.print(serGM[i],HEX);
  }
  Serial.println();

  // DevEUI
  Serial.print(F("DevEUI:"));
  for(i=0;i<8;i++) {
    DEVEUI[i]=EEPROM.read(EEPROM_OFFSET_DEVEUI+i);
    Serial.print(F(" "));
    Serial.print(DEVEUI[i],HEX);
    if(DEVEUI[i]!=0xff)
      virgin=false;
  }
  Serial.println(F(""));
  if(virgin) {
    Serial.println(F("Virgin GMote DevEUI detected!"));
    Serial.print(F("Setting default DevEUI to:"));
    for(i=0;i<8;i++) {
      DEVEUI[i]=serGM[i+2];
      EEPROM.write(EEPROM_OFFSET_DEVEUI+i,serGM[i+2]);
      Serial.print(F(" "));
      Serial.print(DEVEUI[i],HEX);
    }
    Serial.println();
  }

  // AppEUI
  virgin=true;
  Serial.print(F("AppEUI:"));
  for(i=0;i<8;i++) {
    APPEUI[i]=EEPROM.read(EEPROM_OFFSET_APPEUI+i);
    Serial.print(F(" "));
    Serial.print(APPEUI[i],HEX);
    if(APPEUI[i]!=0xff)
      virgin=false;
  }
  Serial.println();
  if(virgin) {
    Serial.println(F("Virgin AppEUI detected!"));
    Serial.print(F("Setting default AppEUI to:"));
    for(i=0;i<8;i++) {
      APPEUI[i]=i;
      EEPROM.write(EEPROM_OFFSET_APPEUI+i,APPEUI[i]);
      Serial.print(F(" "));
      Serial.print(APPEUI[i],HEX);
    }
    Serial.println(F(""));
  }

  // AppKey
  virgin=true;
  Serial.print(F("AppKey:"));
  for(i=0;i<16;i++) {
    APPKEY[i]=EEPROM.read(EEPROM_OFFSET_APPKEY+i);
    Serial.print(F(" "));
    Serial.print(APPKEY[i],HEX);
    if(APPKEY[i]!=0xff)
      virgin=false;
  }
  Serial.println(F(""));
  if(virgin) {
    Serial.println(F("Virgin AppKey detected!"));
    Serial.print(F("Setting default AppKey to:"));
    for(i=0;i<16;i++) {
      APPKEY[i]=i;
      EEPROM.write(EEPROM_OFFSET_APPKEY+i,APPKEY[i]);
      Serial.print(F(" "));
      Serial.print(APPKEY[i],HEX);
    }
    Serial.println(F(""));
  }
  
  // ConfGM
  virgin=true;
  Serial.print(F("ConfGM:"));
  for(i=0;i<8;i++) {
    confGM[i]=EEPROM.read(EEPROM_OFFSET_CONFGM+i);
    Serial.print(F(" "));
    Serial.print(confGM[i],HEX);
    if(confGM[i]!=0xff)
      virgin=false;
  }
  Serial.println();
  if(virgin) {
    Serial.println(F("Virgin GMote config detected!"));
    Serial.print(F("Setting default config to:"));
    for(i=0;i<8;i++) {
      confGM[i]=0;
      EEPROM.write(EEPROM_OFFSET_CONFGM+i,confGM[i]);
      Serial.print(F(" "));
      Serial.print(confGM[i],HEX);
    }
    Serial.println(F(""));
  }

  // GMote state
  state = 0;
  bitSet(state,STARTUP);
  keep_alive_cnt=0;
  keep_alive=confGM[KEEP_ALIVE];

  // LMIC init
  os_init();
  // Reset the MAC state.
  LMIC_reset();

  // Let LMIC compensate for +/- 1% clock error --- required for the 8 MHz Mini Pro
  LMIC_setClockError(MAX_CLOCK_ERROR * 1 / 100);
}

void loop() {

  os_runloop_once();

  if(!(state&bit(STARTUP))) {
    if(!(state&bit(SENDING))) {
      do_send(&sendjob);
    }
  }
  else {
    Serial.println(F("Startup, ready for UART configuration ... "));
    delay(STARTUP_DELAY);
    bitClear(state,STARTUP);
  }

}

void process_uart_cmd() {

  uint8_t eeprom_offset=0;
  uint8_t *ram_ptr;
  uint8_t len;
  uint8_t i=0;
  uint8_t sc=0;
  
  Serial.print(F("S:"));
  for(int i=0;i<inSerCnt;i++) {
    Serial.print(F(" "));
    Serial.print(inSerBuf[i],HEX);
  }
  Serial.println();
  if(inSerCnt<2) {
    Serial.println(F("Command too short!"));
    inSerCnt=0;
    return;
  }

  sc=1;
  while(sc<inSerCnt) {
    
    switch(inSerBuf[sc]) {
      case 'd':
        Serial.print(F("DevEUI"));
        eeprom_offset=0;
        ram_ptr=DEVEUI;
        len=8;
        break;
      case 'a':
        Serial.print(F("AppEUI"));
        eeprom_offset=8;
        ram_ptr=APPEUI;
        len=8;
        break;
      case 'k':
        Serial.print(F("AppKey"));
        eeprom_offset=16;
        ram_ptr=APPKEY;
        len=16;
        break;
      case 'c':
        Serial.print(F("GMote Config"));
        eeprom_offset=32;
        ram_ptr=confGM;
        len=8;
        break;
      default:
        Serial.print(F("unknown command"));
        len=0;
        break;
    }
    sc+=1;
    // write to ram & eeprom
    for(i=0; i<len; i++) {
      Serial.print(F(" "));
      Serial.print(inSerBuf[i+sc],HEX);
      ram_ptr[i]=inSerBuf[i+sc];
      EEPROM.write(eeprom_offset+i,ram_ptr[i]);
    }
    sc+=len;
    Serial.println();
  
  }
  
  // reset serial counter
  inSerCnt=0;
}

void print_eeprom_content(int sAddr,int eAddr) {
  int offset=0;
  if(sAddr>=eAddr)
    return;
  Serial.println(F("EEPROM content:"));
  for(int offset=0;offset<eAddr-sAddr;) {
    if(offset%8==0) {
      Serial.print(offset);
      Serial.print(F(": "));
    }
    else {
      Serial.print(F(" "));
    }
    Serial.print(EEPROM.read(offset),HEX);
    offset+=1;
    if((offset%8==0)||(offset==eAddr-sAddr))
      Serial.println();
  }
}

void enter_sleep() {

  Serial.println(F("Sleep mode"));
  Serial.flush();
  // disable ADC
  ADCSRA=0;
  // clear various "reset" flags
  MCUSR = 0;     
  
  set_sleep_mode(SLEEP_MODE_PWR_DOWN);  
  noInterrupts ();
  // attach int0 isr
  attachInterrupt(0,wakeup,LOW);
  sleep_enable();
  // turn off brown-out enable in software
  MCUCR = bit (BODS) | bit (BODSE);
  MCUCR = bit (BODS); 
  interrupts();
  sleep_cpu();
}

//
// interrupt routines
//
 
void serialEvent() {
  while (Serial.available()) {
    // 1xlength, 3xcmd, 2x8 (appeui & config), 1x16 (appkey)
    if(inSerCnt<36) {
      inSerBuf[inSerCnt]=(char)Serial.read();
      inSerCnt+=1;
      if(inSerCnt-1==inSerBuf[0]) {
        process_uart_cmd();
      }
    }
    else {
      Serial.println(F("Serial Buffer Overflow!"));
      process_uart_cmd();
    }
  }
}

void wakeup() {
  sleep_disable();
  detachInterrupt(0);
  Serial.println(F("Wake up!"));
}

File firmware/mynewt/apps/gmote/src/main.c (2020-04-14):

/**
 * Licensed to the Apache Software Foundation (ASF) under one
 * or more contributor license agreements.  See the NOTICE file
 * distributed with this work for additional information
 * regarding copyright ownership.  The ASF licenses this file
 * to you under the Apache License, Version 2.0 (the
 * "License"); you may not use this file except in compliance
 * with the License.  You may obtain a copy of the License at
 * 
 *  http://www.apache.org/licenses/LICENSE-2.0
 *
 * Unless required by applicable law or agreed to in writing,
 * software distributed under the License is distributed on an
 * "AS IS" BASIS, WITHOUT WARRANTIES OR CONDITIONS OF ANY
 * KIND, either express or implied.  See the License for the
 * specific language governing permissions and limitations
 * under the License.
 */

#include <assert.h>
#include <string.h>

#include "sysinit/sysinit.h"
#include "os/os.h"

#include "bsp/bsp.h"
#include "hal/hal_gpio.h"
#include "hal/hal_spi.h"

#include "node/lora_priv.h"
#include "node/lora.h"

#include "console/console.h"
#include "hal/hal_uart.h"

#ifdef ARCH_sim
#include "mcu/mcu_sim.h"
#endif

#define LORA_TX_OUTPUT_POWER		14	/* dBm */
#define LORA_BANDWIDTH			0	/* 0=125 kHz, ... 2=500 kHz */
#define LORA_SPREADING_FACTOR		7	/* SF7 - SF 12 */
#define LORA_CODING_RATE		1	/* 1 = 4/5, ... 4 = 4/8 */
#define LORA_PREAMBLE_LENGTH		8
#define LORA_SYMBOL_TIMEOUT		5
#define LORA_FIX_LENGTH_PAYLOAD		false
#define LORA_CRC			true
#define LORA_FREQUENCY_HOPPING		0
#define LORA_FREQUENCY_HOPPING_PERIOD	0
#define LORA_IQ_INVERSION		false
#define LORA_TX_TIMEOUT			3000	/* ms */
#define LORA_RX_TIMEOUT			1000	/* ms */
#define LORA_CONTINUOUS_RECEIVE		true
#define LORA_BUFFER_SIZE		64

uint8_t lora_dev_eui[] = {0x00, 0x01, 0x02, 0x03, 0x04, 0x05, 0x06, 0x07};
uint8_t lora_app_eui[] = {0x23, 0x42, 0x02, 0x03, 0x04, 0x05, 0x06, 0x07};
uint8_t lora_app_key[] = {0x00, 0x01, 0x02, 0x03, 0x04, 0x05, 0x06, 0x07,
                          0x00, 0x01, 0x02, 0x03, 0x04, 0x05, 0x06, 0x07};



// lora callbacks
void
gmote_join_cb(LoRaMacEventInfoStatus_t stat, uint8_t att)
{
	console_printf("Joined: status=%d, attempts=%u\n", stat, att);
}
void
gmote_link_check_cb(LoRaMacEventInfoStatus_t stat, uint8_t ngw, uint8_t dm)
{
	console_printf("Link check: status=%d, #GWs=%u, demod_margin=%u\n",
	              stat, ngw, dm);
}

/*
 * main
 *
 */

int
main(int argc, char **argv)
{
    int rc;

#ifdef ARCH_sim
    mcu_sim_parse_args(argc, argv);
#endif

    sysinit();

    /*
     * LoRa
     */

    /*
    RadioEvents_t radio_events;
    
    // radio
    radio_events.TxDone = on_tx_done;
    Radio.Init(&radio_events);

    // frequency
    Radio.SetChannel(868000000);

    // tx and rx config
    Radio.SetTxConfig(MODEM_LORA,
                      LORA_TX_OUTPUT_POWER,
		      0,
                      LORA_BANDWIDTH,
                      LORA_SPREADING_FACTOR,
                      LORA_CODING_RATE,
                      LORA_PREAMBLE_LENGTH,
                      LORA_FIX_LENGTH_PAYLOAD,
		      LORA_CRC,
		      LORA_FREQUENCY_HOPPING,
		      LORA_FREQUENCY_HOPPING_PERIOD,
		      LORA_IQ_INVERSION,
		      LORA_TX_TIMEOUT);

    Radio.SetRxConfig(MODEM_LORA,
                      LORA_BANDWIDTH,
                      LORA_SPREADING_FACTOR,
                      LORA_CODING_RATE,
		      0,
                      LORA_PREAMBLE_LENGTH,
                      LORA_SYMBOL_TIMEOUT,
                      LORA_FIX_LENGTH_PAYLOAD,
		      0,
		      LORA_CRC,
		      LORA_FREQUENCY_HOPPING,
		      LORA_FREQUENCY_HOPPING_PERIOD,
		      LORA_IQ_INVERSION,
		      LORA_CONTINUOUS_RECEIVE);
    */


    /* join callback */
    lora_app_set_join_cb(gmote_join_cb);

    /* link check callback */
    lora_app_set_link_check_cb(gmote_link_check_cb);

    memcpy(g_lora_dev_eui,lora_dev_eui,8);
    memcpy(g_lora_app_key,lora_app_key,16);
    memcpy(g_lora_app_eui,lora_app_eui,8);

    console_printf("GMote on ARM\n");

    rc=lora_app_join(g_lora_dev_eui, g_lora_app_eui, g_lora_app_key, 5);
    if(rc) {
	    console_printf("Join failed: err=%d\n", rc);
    }
    else {
	    console_printf("Joining ...\n");
    }

    int cnt=0;
    char *str="FooBar!";
    char *ptr;

    while (1) {
        /* Wait one second */
        os_time_delay(OS_TICKS_PER_SEC);

        /* hello world */
	console_printf("Hello World! %d\n",cnt);
	ptr=&str[0];
	while(*ptr)
		hal_uart_blocking_tx(1,*ptr++);
	hal_uart_blocking_tx(1,'\n');
	hal_uart_blocking_tx(1,'\r');

	cnt++;
    }
    assert(0);

    return rc;
}

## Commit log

2019-02-26 initial commit of the small and mini GMote KiCad files
    [gmote_mini.kicad_pcb, gmote_mini.sch, gmote_small.kicad_pcb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]
2019-03-31 case + fw and utils dir
    [mini_900.scad, mini_900_bottom.stl, mini_900_ms_closing.stl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]
2019-04-01 added byttery info + schematic jpg
2020-02-21 added selfmade soil moisture sensor
    [sms.kicad_pcb, sms.sch]
2020-02-21 added arm pcb
    [pcb_arm.kicad_pcb, pcb_arm.sch]
2020-02-21 pcb arm README added
2021-11-08 Update README.md
    https://forum.kicad.info/t/warning-avoid-all-links-to-kicad-pcb-org-use-kicad-org/31521
